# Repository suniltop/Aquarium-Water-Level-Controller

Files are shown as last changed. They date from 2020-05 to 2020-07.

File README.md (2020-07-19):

# Aquarium-Water-Level-Controller

Description

* This circuit designed for espically saltwater aquarium lovers.
* Old school design only through hole package type component is used. Thus handmade soldering is easy for all.
* No MCU, No Firmware :)

PCB picture saved from KiCAD with Raytracing

<p align="center">
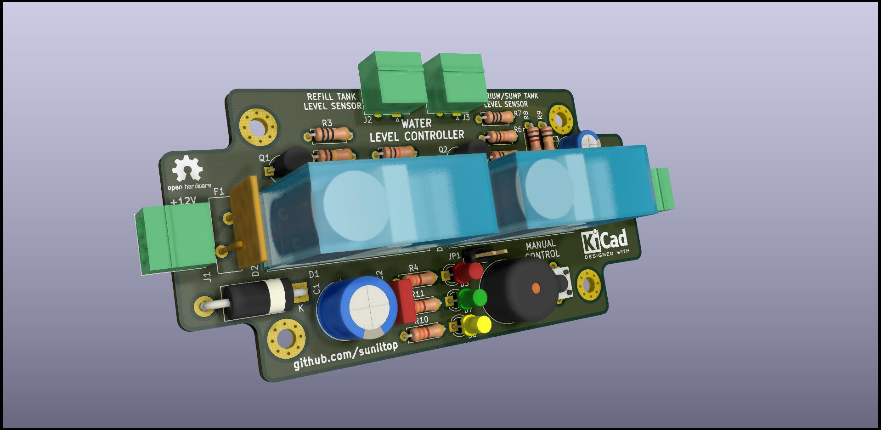
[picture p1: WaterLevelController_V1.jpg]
  
</p>

- Green Led: Everything is fine.
- Yellow Led: Water pump is runnning so, filling aquarium tank or sump tank.
- Red Led: Refill tank is empty.

PCB Picture

<p align="center">
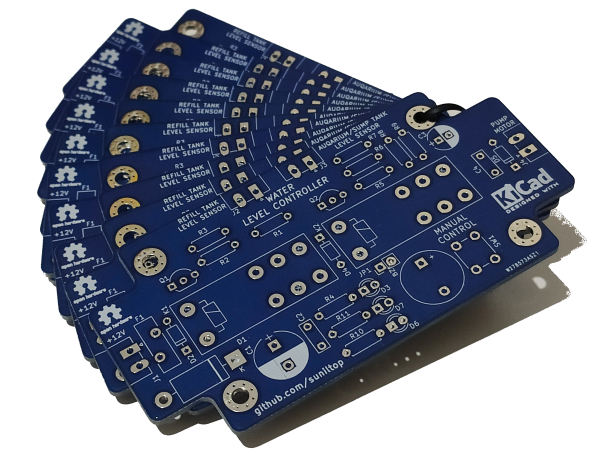
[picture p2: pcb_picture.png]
PCB Picture
  
</p>

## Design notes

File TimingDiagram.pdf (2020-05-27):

Refill
Tank
Sensor

Aquarium
Or
Sump
Sensor

Leds

Manual
Button

Refill tank
İs empty

Tank
is
empty

Pump
Motor | ON

ON

ON

t

t

t

t

t

Sunil TOP

τ | τ

ON

Tank
is
empty

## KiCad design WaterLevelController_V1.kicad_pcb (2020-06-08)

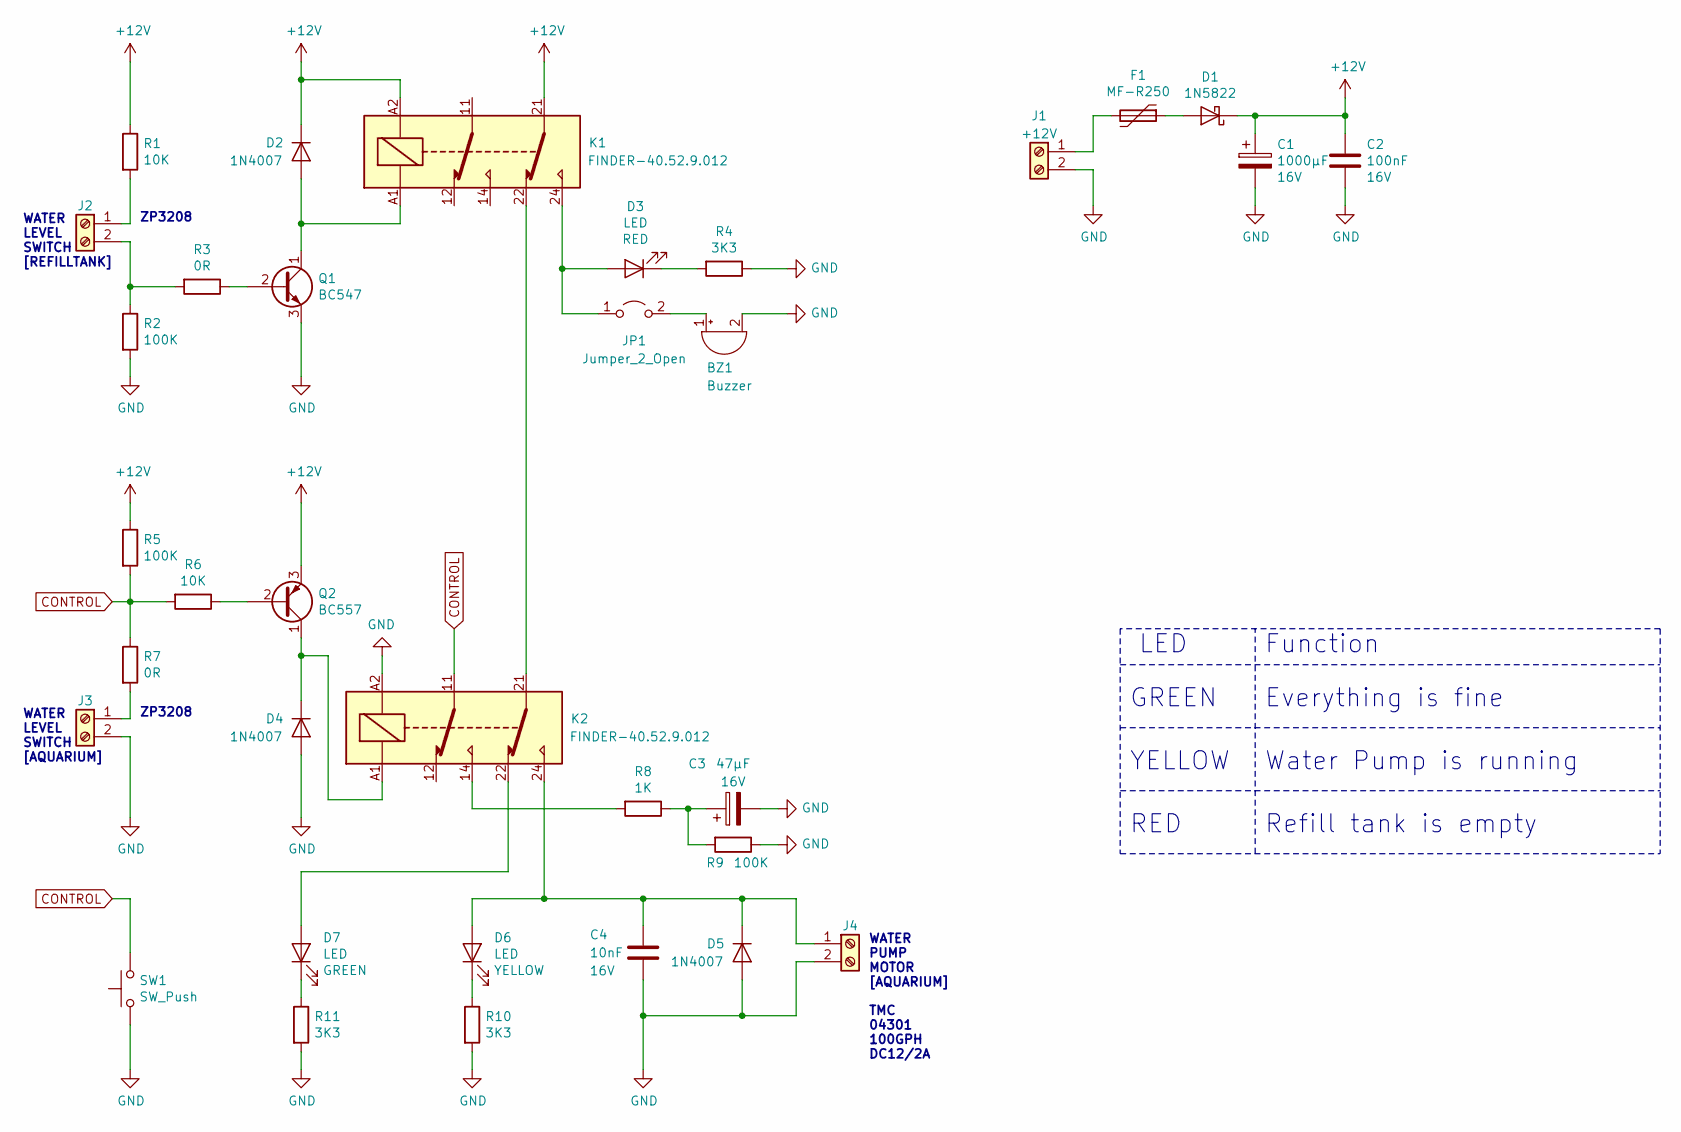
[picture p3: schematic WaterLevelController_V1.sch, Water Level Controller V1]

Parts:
BZ1: Buzzer; Buzzer_12x9.5RM7.6
C1: 1000µF; CP_Radial_D10.0mm_P5.00mm; Voltage 16V
C2: 100nF; C_Rect_L7.0mm_W2.5mm_P5.00mm; Voltage 16V
C3: 47µF; CP_Radial_D6.3mm_P2.50mm; Voltage 16V
C4: 10nF; C_Rect_L7.0mm_W2.5mm_P5.00mm; Voltage 16V
D1: 1N5822; D_DO-201AD_P15.24mm_Horizontal
D2, D4, D5: 1N4007; D_DO-35_SOD27_P7.62mm_Horizontal
D3, D6, D7: LED; LED_D3.0mm_FlatTop
F1: MF-R250; Fuse_Bourns_MF-R250
J1, J2, J3, J4: Screw_Terminal_01x02; PhoenixContact_MC-G_02x3.81mm_Angled
JP1: Jumper_2_Open; PinHeader_1x02_P2.54mm_Vertical
K1, K2: FINDER-40.52.9.012; Relay_DPDT_Finder_40.52
Q1: BC547; TO-92_Inline_Wide
Q2: BC557; TO-92_Inline_Wide
R1, R6: 10K; R_Axial_DIN0207_L6.3mm_D2.5mm_P7.62mm_Horizontal
R2, R5, R9: 100K; R_Axial_DIN0207_L6.3mm_D2.5mm_P7.62mm_Horizontal
R3, R7: 0R; R_Axial_DIN0207_L6.3mm_D2.5mm_P7.62mm_Horizontal
R4, R10, R11: 3K3; R_Axial_DIN0207_L6.3mm_D2.5mm_P7.62mm_Horizontal
R8: 1K; R_Axial_DIN0207_L6.3mm_D2.5mm_P7.62mm_Horizontal
SW1: SW_Push; SW_PUSH_6mm

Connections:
+12V: C1.1, C2.1, D1.1 (K), D2.1 (K), K1.21, K1.A2, Q2.3 (E), R1.1, R5.1
CONTROL: K2.11, R5.2, R6.2, R7.1, SW1.2
GND: BZ1.2 (+), C1.2, C2.2, C3.2, C4.2, D4.2 (A), D5.2 (A), J1.2, J3.2, J4.2, K2.A2, Q1.3 (E), R2.2, R4.1, R9.1, R10.2, R11.2, SW1.1
unnamed: BZ1.1 (-), JP1.2 (B)
unnamed: C3.1, R8.1, R9.2
unnamed: C4.1, D5.1 (K), D6.2 (A), J4.1, K2.24
unnamed: D1.2 (A), F1.1
unnamed: D2.2 (A), K1.A1, Q1.1 (C)
unnamed: D3.1 (K), R4.2
unnamed: D3.2 (A), JP1.1 (A), K1.24
unnamed: D4.1 (K), K2.A1, Q2.1 (C)
unnamed: D6.1 (K), R10.1
unnamed: D7.1 (K), R11.1
unnamed: D7.2 (A), K2.22
unnamed: F1.2, J1.1
unnamed: J2.1, R1.2
unnamed: J2.2, R2.1, R3.2
unnamed: J3.1, R7.2
unnamed: K1.22, K2.21
unnamed: K2.14, R8.2
unnamed: Q1.2 (B), R3.1
unnamed: Q2.2 (B), R6.1

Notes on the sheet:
LED
GREEN
YELLOW
RED
WATER LEVEL SWITCH [AQUARIUM]
WATER LEVEL SWITCH [REFILLTANK]
WATER PUMP MOTOR [AQUARIUM]
Water Pump is running
Everything is fine
Refill tank is empty
Function
ZP3208
TMC 04301 100GPH DC12/2A

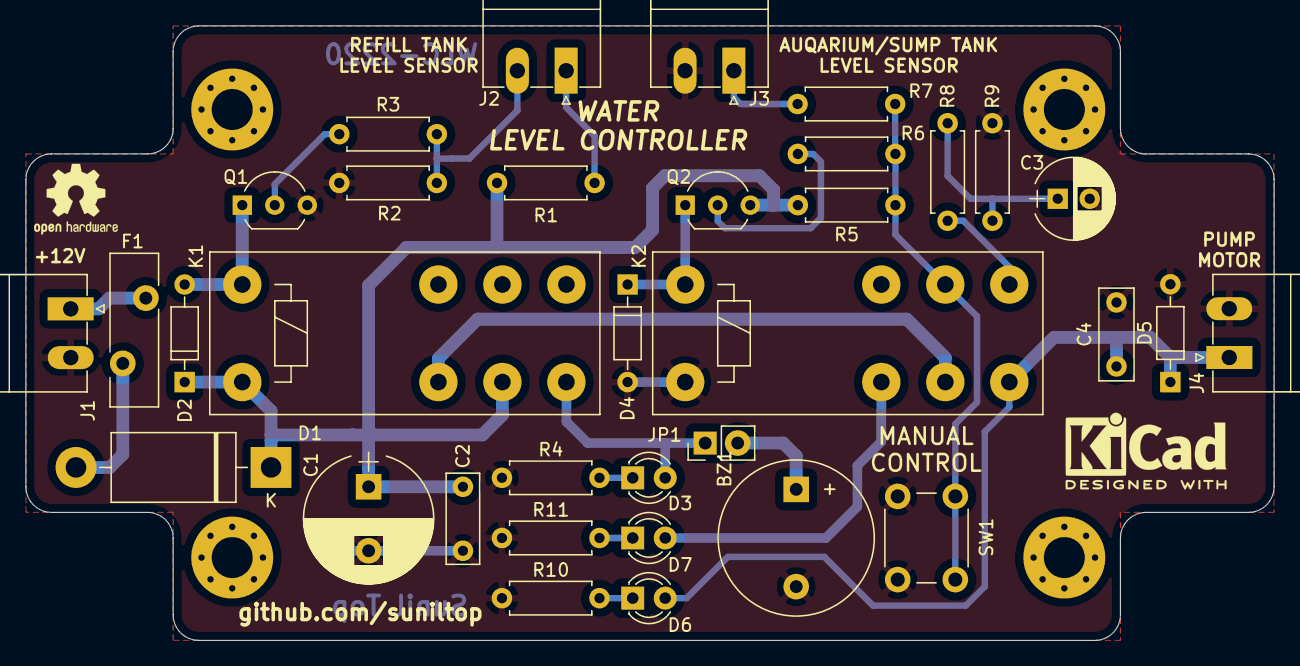
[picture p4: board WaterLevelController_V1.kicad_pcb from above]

Board: 2 copper layers, 97.5 x 48.0 mm, 34 parts (0 on the bottom side), 22 nets.

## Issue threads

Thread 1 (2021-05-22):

Wrong Resistors Values

suniltop, 2021-05-22:
[https://github.com/suniltop/Aquarium-Water-Level-Controller/commit/2fe55659e8430126c9a2ed6414e215f37d7471fa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](url)

drumow, 2021-05-31:
Hi  Friend i have created your project, thanks very useful but when the pump is activated and sensor is deactivated the pump keeps on working does not turn off, Can you please help me.

Thanks

drumow, 2021-05-31:
Worked perfectly thanks what does the refill tank sensor do just make a sound?

Thanks

suniltop, 2021-05-31:
Thank for interest.
* Pump on/off control has a hysteresis. If it is unusable or unrequirments for you, you should remove C3, but i do not recommend because we need a hystersis for controlling a pump in real application
* Refill tank sensor is not only for sound alarm. In basically it allows pump voltage. Because we dont want run pump if refill task is empty. If we dont do that, pump is maybe broken

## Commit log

2020-05-27 Add files via upload
    Uploaded version WLC-2220 schmatic, pcb, timing diagram files.
    [WaterLevelController_V1.kicad_pcb, WaterLevelController_V1.sch]
2020-05-27 Update README.md
    Adding PCB Picture
2020-05-27 Update README.md
    Led working description has been added.
2020-06-08 Add files via upload
    Added PTC type Resettable Fuse to voltage input
    [WaterLevelController_V1.kicad_pcb, WaterLevelController_V1.sch]
2020-06-08 Add files via upload
    Added gerber files for PCB Production
    [WaterLevelController_V1-B_Cu.gbl, WaterLevelController_V1-B_Mask.gbs, WaterLevelController_V1-B_SilkS.gbo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]
2020-07-19 Added pcb picture
